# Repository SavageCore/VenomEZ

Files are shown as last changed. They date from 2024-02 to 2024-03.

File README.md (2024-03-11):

# VenomEZ
> GP2040-CE powered EZ Mod for Venom PS3/PS4 Arcade Stick

**TESTING** - do not order yet! v1.2 has just been delivered, Player LEDs are still not working, however, the rest of the board is fully functional (including Turbo LED!) and fitment is finally good. I'm working on a new version of the board, v1.3, which will fix the LED issues. Further down the line I'll rework to also add the USB connector found on the stock board so you can choose USB-C or not. Personally I am adding a Neutrik connector to my stick, so I don't need the stock connector.

"EZ" mod for the [Venom PS3/PS4 Arcade Stick](https://imgur.com/rmCg5gm), using the RP2040 microcontroller and [GP2040-CE](https://github.com/OpenStickCommunity/GP2040-CE) firmware. It's a drop-in replacement for the existing PCB, apart from the change to a USB-C connector.

## Firmware

Builds can be found [here](https://github.com/SavageCore/GP2040-CE/actions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) - these are pre-release builds and may not be stable and may lag behind the main branch.

VenomEZ
VenomEZ-back

## Pins

| GPIO | Function |
| --- | --- |
17 | Up
16 | Down
14 | Left
15 | Right
5 | B1 / A / B / Cross / 2 / K1
6 | B2 / B / A / Circle / 3 / K2
13 | R2 / RT / ZR / R2 / 8 / K3
11 | L2 / LT / ZL / L2 / 7 / K4
7 | B3 / X / Y / Square / 1 / P1
8 | B4 / Y / X / Triangle / 4 / P2
12 | R1 / RB / R / R1 / 6 / P3
10 | L1 / LB / L / L1 / 5 / P4
19 | S1 / Back / Minus / Select / 9 / Coin
18 | S2 / Start / Plus / Start / 10 / Start
9 | A1 / Guide / Home / PS / 13 / ~
20 | A2 / ~ / Capture / ~ / 14 / ~
21 | Turbo
22 | LS/DP Toggle Switch (bound to LS slider add-on, LS position = D-Pad, DP = LS)
23 | Turbo 1/2 Toggle Switch (bound to RS slider add-on, Turbo 2 position = D-Pad, Turbo 1 = RS)
24 | PS3/PS4 Toggle Switch (bound to Focus Mode add-on, disables Start/Select/PS buttons)
25 | Player LED 1
26 | Player LED 2
27 | Player LED 3
28 | Player LED 4
29 | Turbo LED

## Ordering your own boards

1. Go to [JLCPCB](https://jlcpcb.com/)

2. Click on `Instant Quote`

3. Click on `Add Gerber file` and choose the file named `GERBER-VenomEZ.zip`
 from [Releases](https://github.com/SavageCore/VenomEZ/releases/latest)

4. Choose the following options for the board:

* Base Material = FR-4
* Layers = 2
* Dimensions = (should auto-populate) 71.97 mm x 41.99 mm
* PCB Qty = 5 (or more)
* Product Type = Industrial/Consumer electronics
* Different Design = 1
* Delivery Format = Single PCB
* PCB Thickness = 1.6
* PCB Color = Whatever you want
* Silkscreen = N/A
* Surface Finish = HASL(with lead)
* Outer Copper Weight = 1oz
* Via Covering = Tented
* Board Outline Tolerance = +/- 0.2mm (Regular)
* Confirm Production file = Yes
* **Remove Order Number = Specify a location**
* Flying Probe Test = Fully Test
* Gold Fingers = No
* Castellated Holes = No
* Edge Plating = No

Advanced options: (I left these as default)

* 4-Wire Kelvin Test = No
* Paper between PCBs = No
* Appearance Quality = IPC Class 2 Standard
* Silkscreen Technology = Ink-jet/Screen Printing Silkscreen
* Package Box = With JLCPCB logo

PCB Assembly:

* PCBA Type = Economic
* Assembly Side = Top Side
* PCBA Qty = (the same as PCB Qty)
* Tooling holes = Added by JLCPCB
* Confirm Parts Placement = Yes

## This is what we're replacing:



[][cc-by-sa]

[cc-by-sa]: http://creativecommons.org/licenses/by-sa/4.0/
[cc-by-sa-shield]: https://img.shields.io/badge/License-CC%20BY--SA%204.0-lightgrey.svg

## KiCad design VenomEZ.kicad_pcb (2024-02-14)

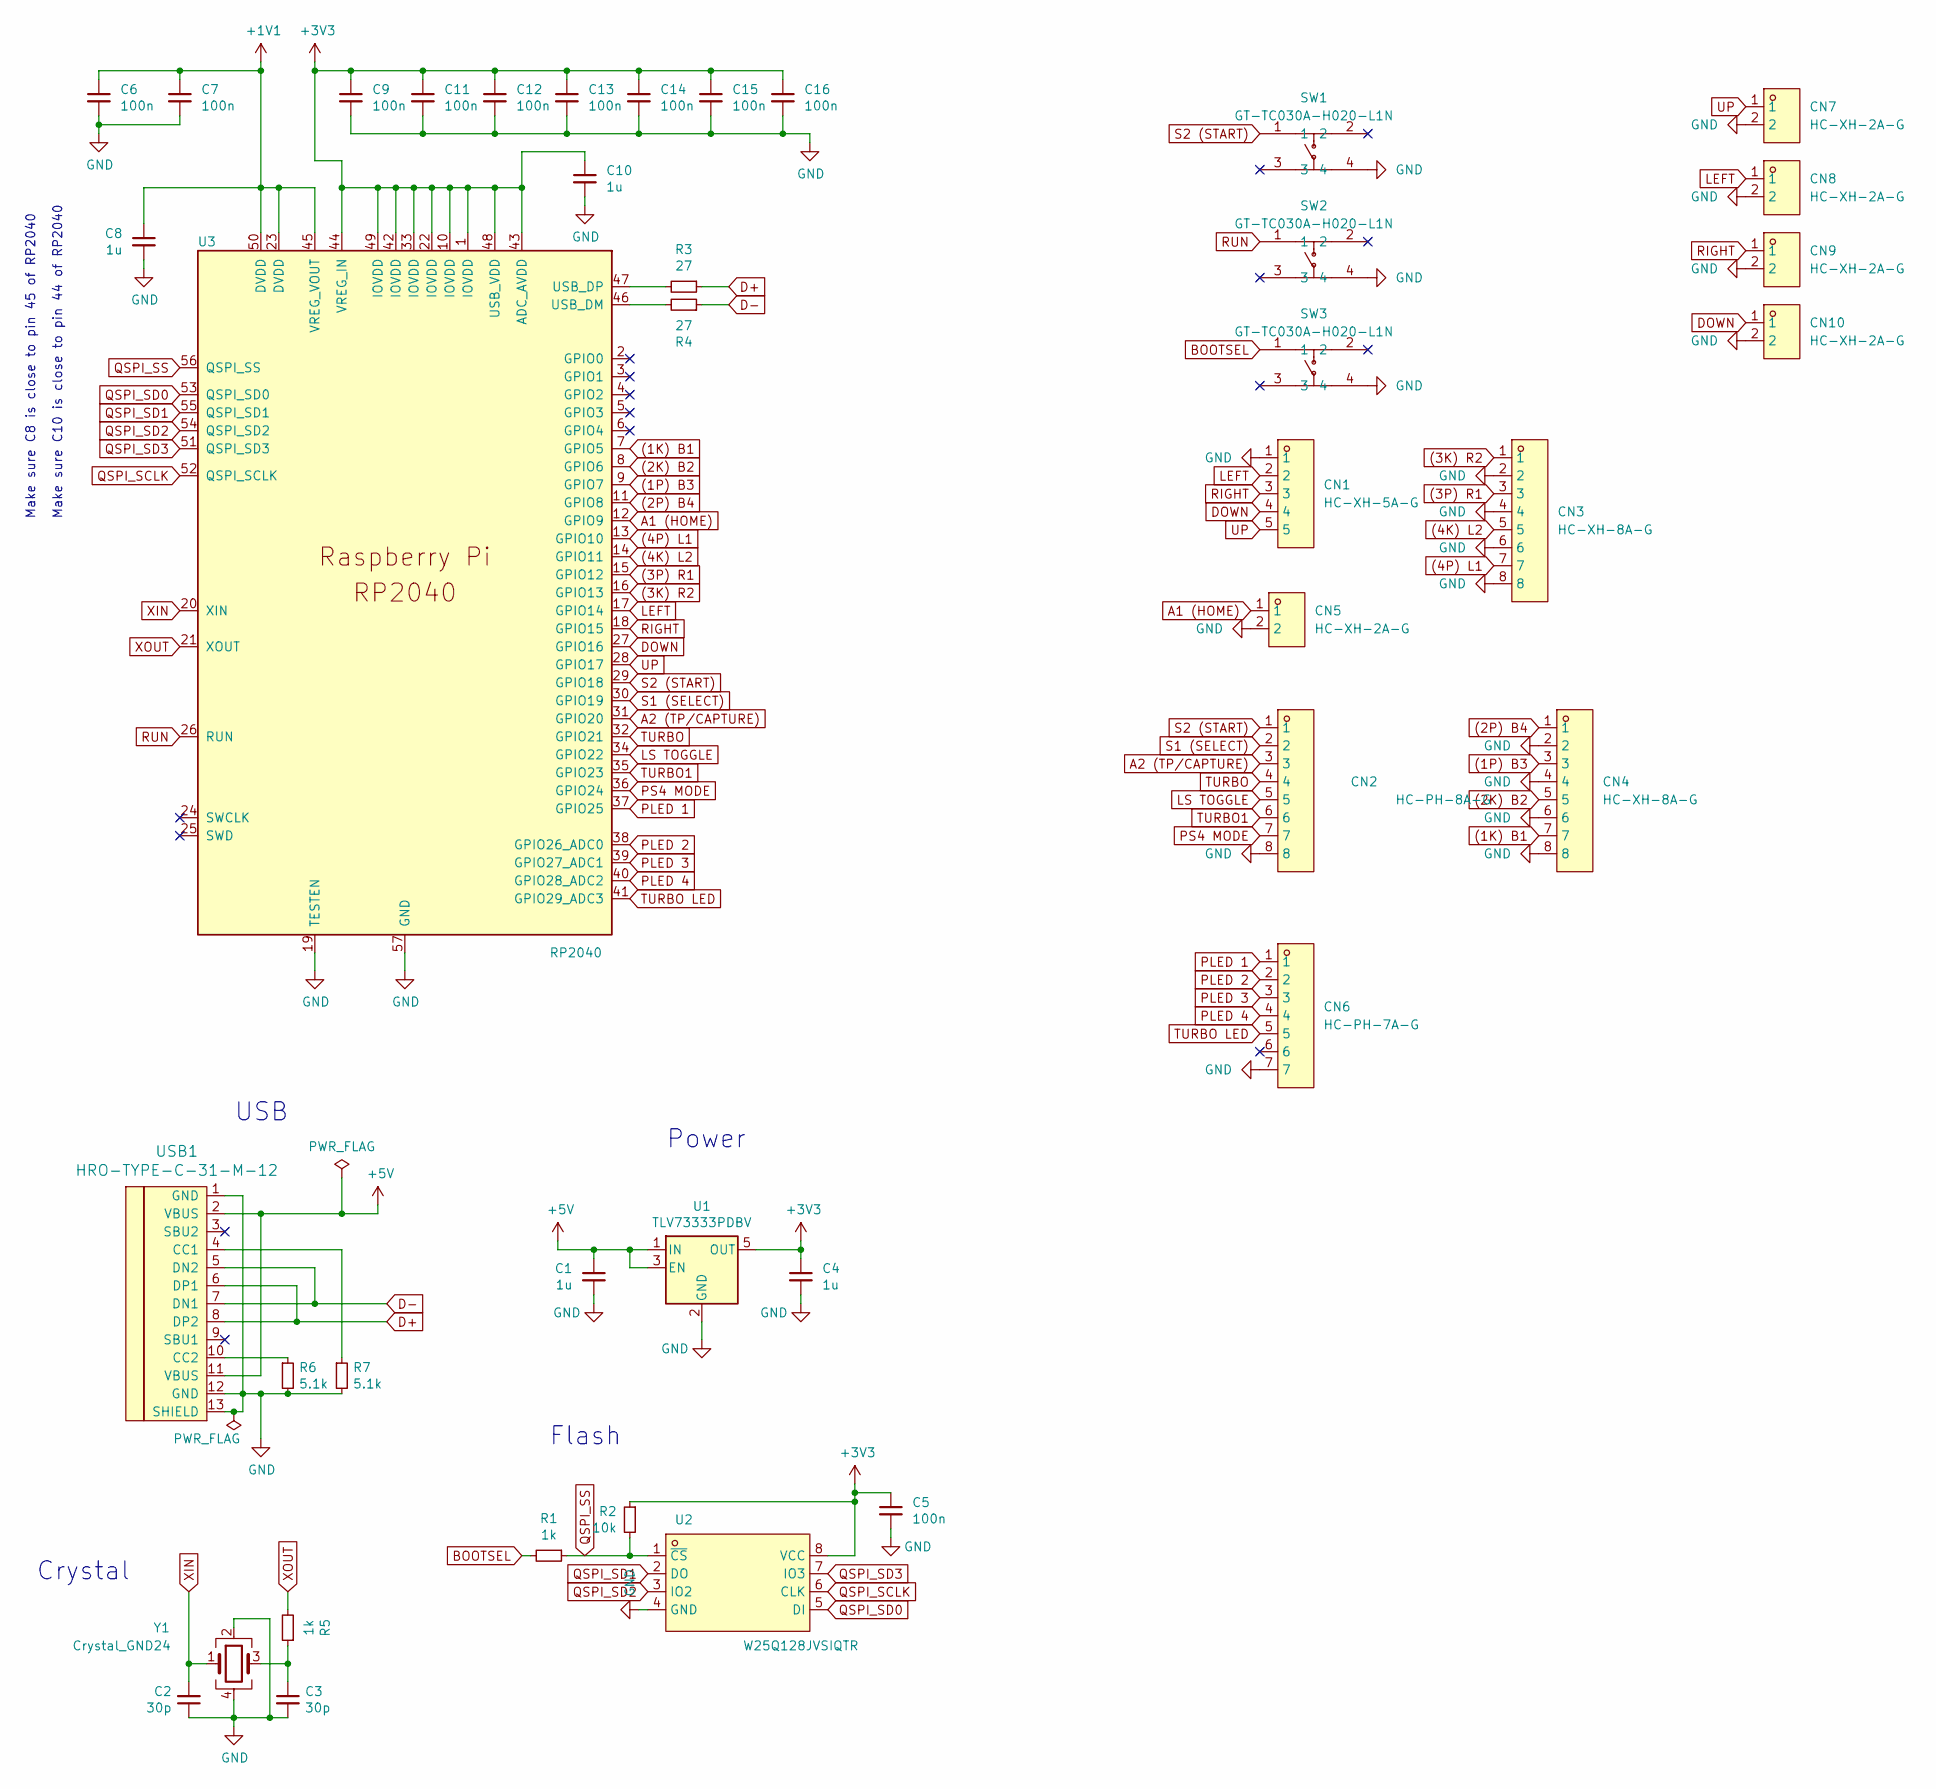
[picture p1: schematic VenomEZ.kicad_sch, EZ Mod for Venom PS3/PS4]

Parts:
C1, C4, C8, C10: 1u; C_0402_1005Metric; LCSC C52923
C2, C3: 30p; C_0402_1005Metric; LCSC C1570
C5, C6, C7, C9, C11, C12, C13, C14, C15, C16: 100n; C_0402_1005Metric; LCSC C1525
CN1: HC-XH-5A-G; CONN-TH_5P-P2.50_HC-XH-5A-G; LCSC Part C5341204
CN2: HC-PH-8A-G; CONN-TH_8P-P2.00_PH-8A; LCSC Part C33476
CN3, CN4: HC-XH-8A-G; CONN-TH_8P-P2.50_HCTL_XH-8A_C2908606; LCSC Part C5341207
CN5, CN7, CN8, CN9, CN10: HC-XH-2A-G; CONN-TH_2P-P2.50_HC-XH-2A-G; LCSC Part C5341201
CN6: HC-PH-7A-G; CONN-TH_7P-P2.00_PH-7A; LCSC Part C10398
R1, R5: 1k; R_0402_1005Metric; LCSC C11702
R2: 10k; R_0402_1005Metric; LCSC C25744
R3, R4: 27; R_0402_1005Metric; LCSC C138021
R6, R7: 5.1k; R_0402_1005Metric; LCSC C25905
SW1, SW2, SW3: GT-TC030A-H020-L1N; SW-SMD_4P-L3.6-W3.0-P1.50-LS4.7; LCSC Part C843670
U1: TLV73333PDBV; SOT-23-5; LCSC C134139
U2: W25Q128JVSIQTR; SOIC-8_L5.3-W5.3-P1.27-LS8.0-BL; LCSC Part C97521
U3: RP2040; RP2040-QFN-56; LCSC C2040
USB1: HRO-TYPE-C-31-M-12; HRO-TYPE-C-31-M-12-Assembly; LCSC C165948
Y1: Crystal_GND24; Crystal_SMD_3225-4Pin_3.2x2.5mm; LCSC C9002

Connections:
(1K) B1: CN4.7, U3.7 (GPIO5)
(1P) B3: CN4.3, U3.9 (GPIO7)
(2K) B2: CN4.5, U3.8 (GPIO6)
(2P) B4: CN4.1, U3.11 (GPIO8)
(3K) R2: CN3.1, U3.16 (GPIO13)
(3P) R1: CN3.3, U3.15 (GPIO12)
(4K) L2: CN3.5, U3.14 (GPIO11)
(4P) L1: CN3.7, U3.13 (GPIO10)
+1V1: C6.1, C7.1, C8.1, U3.23 (DVDD), U3.45 (VREG_VOUT), U3.50 (DVDD)
+3V3: C4.1, C5.1, C9.1, C10.1, C11.1, C12.1, C13.1, C14.1, C15.1, C16.1, R2.1, U1.5 (OUT), U2.8 (VCC), U3.1 (IOVDD), U3.10 (IOVDD), U3.22 (IOVDD), U3.33 (IOVDD), U3.42 (IOVDD), U3.43 (ADC_AVDD), U3.44 (VREG_IN), U3.48 (USB_VDD), U3.49 (IOVDD)
+5V: C1.1, U1.1 (IN), U1.3 (EN), USB1.2 (VBUS), USB1.11 (VBUS)
A1 (HOME): CN5.1, U3.12 (GPIO9)
A2 (TP/CAPTURE): CN2.3, U3.31 (GPIO20)
BOOTSEL: R1.2, SW3.1
D+: R3.1, USB1.6 (DP1), USB1.8 (DP2)
D-: R4.1, USB1.5 (DN2), USB1.7 (DN1)
DOWN: CN1.4, CN10.1, U3.27 (GPIO16)
GND: C1.2, C2.1, C3.2, C4.2, C5.2, C6.2, C7.2, C8.2, C9.2, C10.2, C11.2, C12.2, C13.2, C14.2, C15.2, C16.2, CN1.1, CN2.8, CN3.2, CN3.4, CN3.6, CN3.8, CN4.2, CN4.4, CN4.6, CN4.8, CN5.2, CN6.7, CN7.2, CN8.2, CN9.2, CN10.2, R6.2, R7.2, SW1.4, SW2.4, SW3.4, U1.2 (GND), U2.4 (GND), U3.19 (TESTEN), U3.57 (GND), USB1.1 (GND), USB1.12 (GND), USB1.13 (SHIELD), Y1.2, Y1.4
LEFT: CN1.2, CN8.1, U3.17 (GPIO14)
LS TOGGLE: CN2.5, U3.34 (GPIO22)
unnamed: C3.1, R5.1, Y1.3
unnamed: R4.2, U3.46 (USB_DM)
unnamed: R3.2, U3.47 (USB_DP)
unnamed: R7.1, USB1.4 (CC1)
unnamed: R6.1, USB1.10 (CC2)
PLED 1: CN6.1, U3.37 (GPIO25)
PLED 2: CN6.2, U3.38 (GPIO26_ADC0)
PLED 3: CN6.3, U3.39 (GPIO27_ADC1)
PLED 4: CN6.4, U3.40 (GPIO28_ADC2)
PS4 MODE: CN2.7, U3.36 (GPIO24)
QSPI_SCLK: U2.6 (CLK), U3.52 (QSPI_SCLK)
QSPI_SD0: U2.5 (DI), U3.53 (QSPI_SD0)
QSPI_SD1: U2.2 (DO), U3.55 (QSPI_SD1)
QSPI_SD2: U2.3 (IO2), U3.54 (QSPI_SD2)
QSPI_SD3: U2.7 (IO3), U3.51 (QSPI_SD3)
QSPI_SS: R1.1, R2.2, U2.1 (~CS), U3.56 (QSPI_SS)
RIGHT: CN1.3, CN9.1, U3.18 (GPIO15)
RUN: SW2.1, U3.26 (RUN)
S1 (SELECT): CN2.2, U3.30 (GPIO19)
S2 (START): CN2.1, SW1.1, U3.29 (GPIO18)
TURBO: CN2.4, U3.32 (GPIO21)
TURBO1: CN2.6, U3.35 (GPIO23)
TURBO LED: CN6.5, U3.41 (GPIO29_ADC3)
UP: CN1.5, CN7.1, U3.28 (GPIO17)
XIN: C2.2, U3.20 (XIN), Y1.1
XOUT: R5.2, U3.21 (XOUT)

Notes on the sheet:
Crystal
USB
Make sure C8 is close to pin 45 of RP2040
Power
Make sure C10 is close to pin 44 of RP2040
Flash

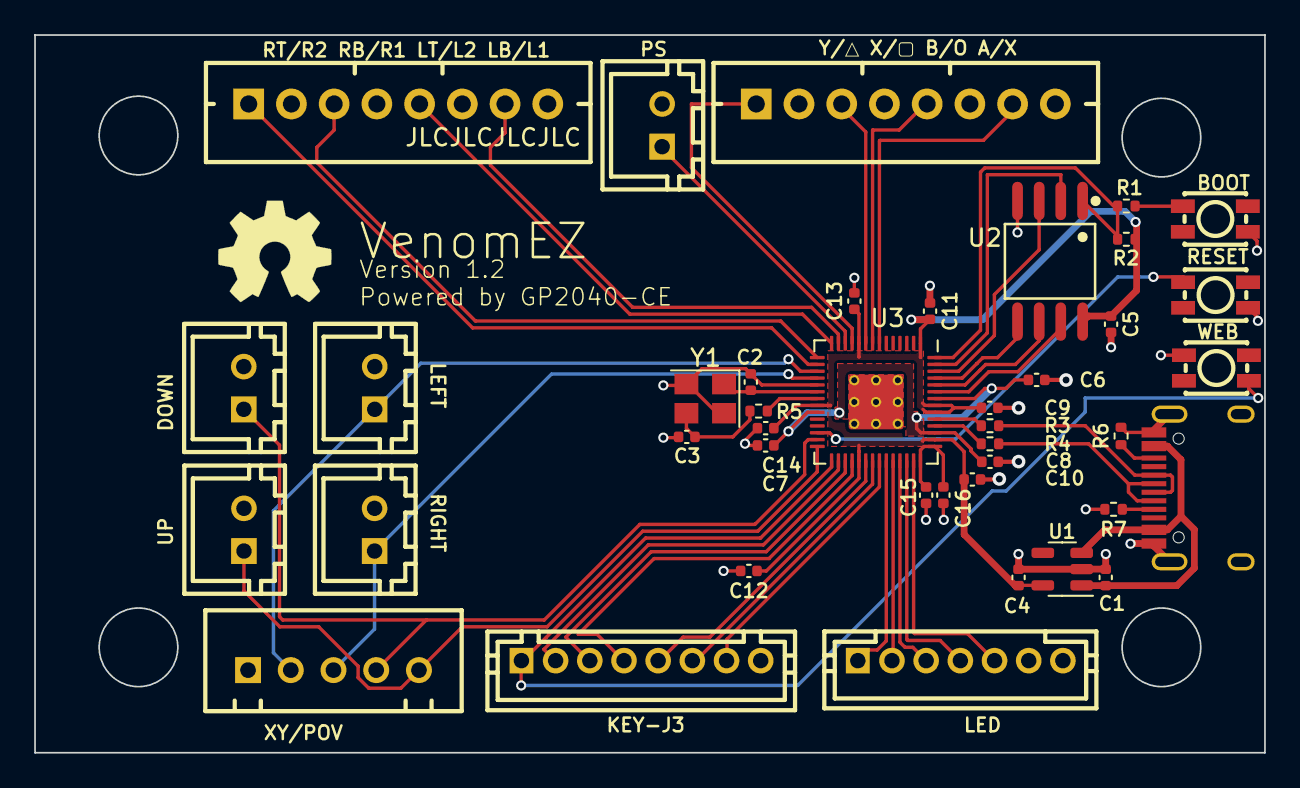
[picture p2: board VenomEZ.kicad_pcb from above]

Board: 2 copper layers, 72.0 x 42.0 mm, 42 parts (0 on the bottom side), 46 nets.

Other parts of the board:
OSHW1: OSHW-Symbol_6.7x6mm_SilkScreen

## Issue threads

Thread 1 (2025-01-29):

New 1.3?

Aljenci, 2025-01-29:
Hello!

First, thank you for creating the open-source PCB project to enhance the Venom Arcade Stick. The work you’ve done so far looks incredibly!

I noticed the README mentions that v1.2 is functional except for Player LEDs, with fitment improvements already in place. While the current version seems viable, I wanted to ask: Are you still planning to release v1.3 to address the remaining LED issues and USB connector integration? Or has the project been paused indefinitely?

Even with the minor limitations of v1.2, the board is functional. I’m strongly considering ordering it as-is, but I’d love to know if v1.3 is still on the horizon.

Either way, thank you for contributing such a valuable project!

Regards

SavageCore, 2025-01-30:
Hi

Thanks for the kind words, I'm glad people are finding this useful!

I'm at a bit of a loss with Player LEDs and haven't had to time to work on it further. As you say 1.2 works fine apart from that, it's in both of my sticks! The only thing I'd like is standard USB connector as well for true plug and play, I've yet to properly mod my sticks for USB-C... but it works!

I can't say when I'll get around to adding the USB connector or fixing PLEDs. Need to dig out the ol breadboard again haha.

If neither of those are a breaking issue for you I'd say go ahead. Heck, I have spare v1.2s populated. Pay for shipping and you can have them?

Aljenci, 2025-01-31:
Hello,

Thank you very much! I just found an old Pi Pico, and I’m going to try adapting some cables to fit inside the Venom. It’s not as convenient as your solution, but I think it will work.

I really appreciate the spare v1.2s, but for now, I’ll first try using the Pi Pico directly. If I run into any issues, I’ll reach out to you on Discord.

Regarding the LEDs, I found the "LED Configuration" page in the GP2040 documentation, specifically the "Player LEDs (XInput)" section. It looks like it’s possible to configure a standard LED on any GPIO pin, so I plan to use GP22, GP26, GP27, and GP28. Hopefully, I can get the LEDs working that way.

I’m not sure if this applies to your board, but once I have some time to test, I can update you on my progress with the LEDs.

Have a great day!

Aljenci, 2025-02-20:
Hello!

I just finished setting up the extra buttons and LEDs. I added the LEDs as I mentioned in my last comment and configured the pins accordingly in the LED settings. The LEDs are also set to PWM mode.

Aside from that, I properly configured the turbo button and LED, and everything related to turbo is working correctly.

However, I'm not sure how to properly test the player LEDs. In the web configuration, all player LEDs are on, but when connected in controller mode, all are on except Player 1, which is off. It seems like they are inverted, but I’m not sure how to configure this.

I also tried connecting as Player 2, etc., but the same LEDs remain on and off regardless.

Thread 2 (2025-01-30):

Fix Player LEDs

SavageCore, 2025-01-30:

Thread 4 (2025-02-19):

Firmware download?

AyanamiRei1, 2025-02-19:
The artifact isn't available for it anymore and the website for the GP2040-CE doesn't have the VenomEZ listed

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

SavageCore, 2025-03-03:
Sorry I missed this, will update to the latest firmware and post an artifact later on today!

AyanamiRei1, 2025-03-03:
Hi I actually sent you a message on discord about some pre assembled boards
you mentioned you had in another issue.

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

SavageCore, 2025-03-03:
Latest build here: https://github.com/SavageCore/GP2040-CE/actions/runs/13637319577/artifacts/2683521297

Oh I'm terrible at checking Discord! Responded now.

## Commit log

2023-07-10 WIP KiCad files
    [Venom.kicad_pcb, Venom.kicad_sch]
2023-07-10 Add ground fill
    [Venom.kicad_pcb, Venom.kicad_sch]
2023-07-10 Add logos
    [Venom.kicad_pcb]
2023-07-10 Add version to silk, move github link to back of board
    [Venom.kicad_pcb]
2023-07-11 Add WEB button
    [Venom.kicad_pcb, Venom.kicad_sch]
2023-07-11 Add RESET button
    [Venom.kicad_pcb, Venom.kicad_sch]
2023-07-11 LEDs need a resistor not capacitor?
    [Venom.kicad_pcb, Venom.kicad_sch]
2023-07-11 Change silk
    [Venom.kicad_pcb, Venom.kicad_sch]
2023-07-11 WIP embedded design
    [Venom.kicad_pcb, Venom.kicad_sch]
2023-07-11 Potentially finished RP2040
    [Venom.kicad_pcb]
2023-07-12 Nearly all wired up?
    [Venom.kicad_pcb, Venom.kicad_sch]
2023-07-12 Add individual up, down, left and right connectors
    [Venom.kicad_pcb, Venom.kicad_sch]
2023-07-12 Update silk
    [Venom.kicad_pcb]
2023-07-12 No DRC errors!
    [Venom.kicad_pcb]
2023-07-12 Rename project files to VenomEZ
    [VenomEZ.kicad_pcb, VenomEZ.kicad_sch]
2023-07-12 Bring easyeda2kicad files into the project directory
    [VenomEZ.kicad_pcb, VenomEZ.kicad_sch]
2023-07-12 Silk updates
    [VenomEZ.kicad_pcb]
2023-07-13 Add hidden "JLCJLCJLCJLC"
    [VenomEZ.kicad_pcb]
2023-07-13 Update PH connectors to ones JLC stock
    [VenomEZ.kicad_pcb, VenomEZ.kicad_sch]
2023-07-13 Update new PH connectors 3d model file paths
    [VenomEZ.kicad_pcb]
2023-07-14 Remove unnecessary ground traces between direction headers
    [VenomEZ.kicad_pcb]
2023-07-14 Update some traces for better look
    [VenomEZ.kicad_pcb]
2023-07-31 Further silk improvements
    [VenomEZ.kicad_pcb]
2023-07-31 Most likely fixed LED. Mounting holes enlarged.
    [VenomEZ.kicad_pcb, VenomEZ.kicad_sch]
2023-07-31 Move web button up to the boot and reset buttons
    [VenomEZ.kicad_pcb]
2023-07-31 Add gp2040-ce logo to rear of board
    [VenomEZ.kicad_pcb]
2023-07-31 Remove CN2 from silk
    [VenomEZ.kicad_pcb]
2023-08-01 I think this is the correct mounting hole size!
    [VenomEZ.kicad_pcb]
2023-08-02 Correct LED pins
    [VenomEZ.kicad_pcb, VenomEZ.kicad_sch]
2023-08-07 Bump revision of schematic
    [VenomEZ.kicad_sch]
2023-08-19 Enlarge mounting holes slightly
    They're a little tight fitting on v1.1
    [VenomEZ.kicad_pcb]
2024-02-14 Move buttons and R1/R2 for better clearance around screw
    [VenomEZ.kicad_pcb]

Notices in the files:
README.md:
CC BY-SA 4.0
